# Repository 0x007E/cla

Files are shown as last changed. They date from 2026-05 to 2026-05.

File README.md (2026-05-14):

  

# `RCL` - RGB Color Lamp

The `RCL` is a board with a set of [APA102](#additional-information) or any other `SPI` controllable `RGB-LED`. The board itself is driven with `5V` over USB and can be configured with the integrated UART interface ([MCP2221A](#additional-information)). The `Color Lamp` itself is controlled over the additional `Touchpad` ([TPD](https://github.com/0x007e/tpd/)) and can be switched on/off over a slide switch.

| Experience  | Level |
|:---|:---:|
| Soldering | ?% |

# Downloads

| Type | File | Description |
|:---:|:---:|:---|
| Schematic | [pdf](https://github.com/0x007E/rcl/releases/latest/download/schematic.pdf) / [cadlab](https://cadlab.io/project/30341/main/files) | Schematic files |
| Board | [pdf](https://github.com/0x007E/rcl/releases/latest/download/pcb.pdf) / [cadlab](https://cadlab.io/project/30341/main/files) | Board file |
| Drill | [pdf](https://github.com/0x007E/rcl/releases/latest/download/drill.pdf) | Drill file |
| PCB | [zip](https://github.com/0x007E/rcl/releases/latest/download/kicad.zip) / [tar](https://github.com/0x007E/rcl/releases/latest/download/kicad.tar.gz) | KiCAD/Gerber/BoM/Drill files |
| Mechanical | [zip](https://github.com/0x007E/rcl/releases/latest/download/freecad.zip) / [tar](https://github.com/0x007E/rcl/releases/latest/download/freecad.tar.gz) | FreeCAD/Housing and exported step/stl files |

# Hardware

The pcb is created with `KiCAD`, the housing with `FreeCAD`. All files are built with `github actions` so that they are ready for a production environment.

## PCB

The circuit board is populated on both sides (Top, Bottom). The best way for soldering the `SMD` components is within a vapor phase soldering system and for the `THT` components with a standard soldering system.

### Top Layer

Top Layer

### Bottom Layer

Bottom Layer

## Mechanical

The housing has a tolerance of `0.2mm` on each side of the case. So the pcb should fit perfectly in the housing. The tolerance can be modified with `FreeCAD` in the `Parameter` Spreadsheet.

### Assembled

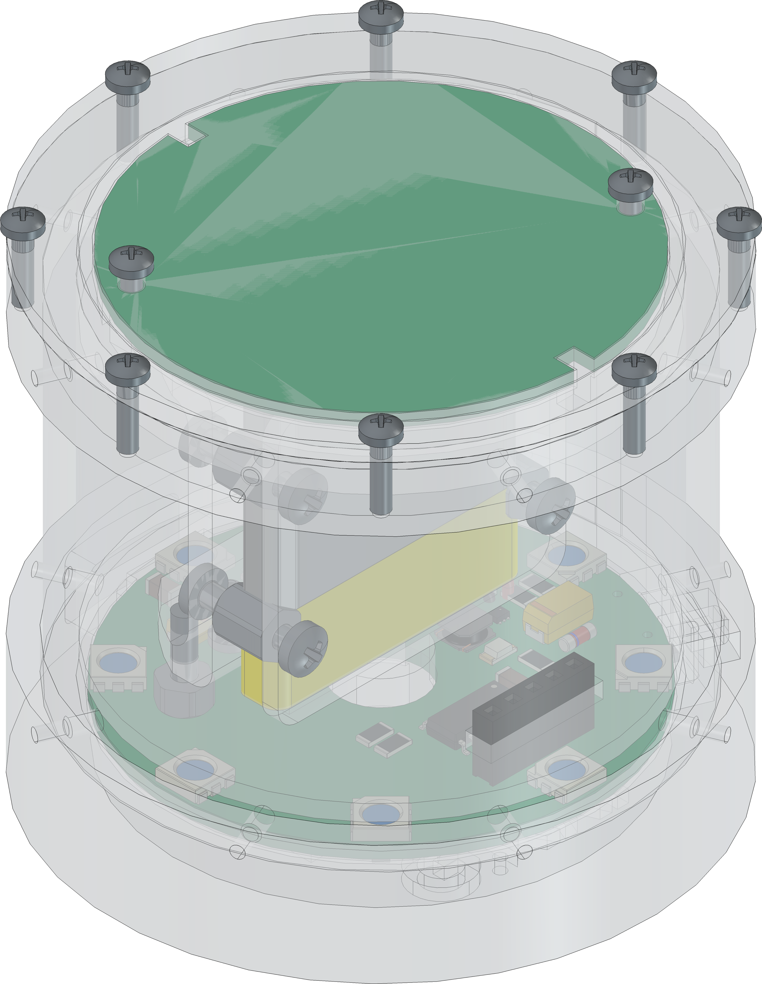
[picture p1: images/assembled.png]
Assembled


### Exploded

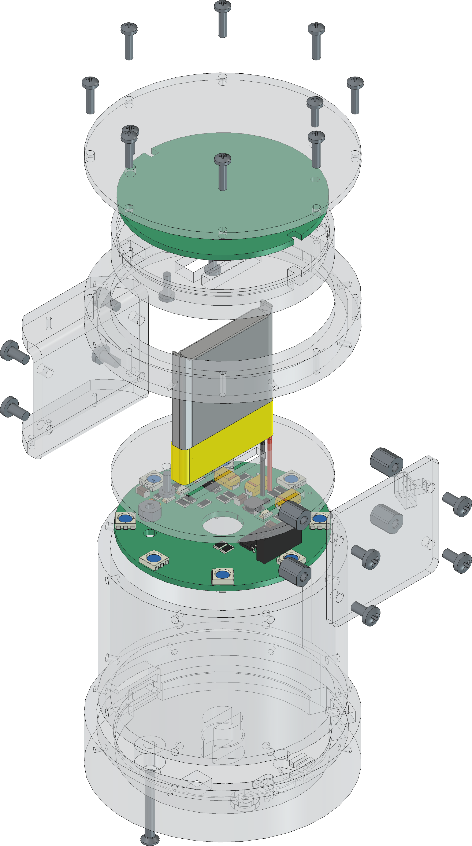
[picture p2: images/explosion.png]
Exploded


# Additional Information

| Type | Link | Description |
|:---:|:---:|:---|
| APA102 | [pdf](https://cdn.sparkfun.com/datasheets/Components/LED/APA102C.pdf) | RGB Full Color LED |
| T3A33BRG | [pdf](https://mm.digikey.com/Volume0/opasdata/d220001/medias/docus/6794/3147_T3A33BRG-H9C0002X1U1930.pdf) | Harvatek Surface Mount PLCC IC+RGB LEDs Data Sheet |
| MCP2221A | [pdf](https://ww1.microchip.com/downloads/en/devicedoc/20005565b.pdf) | USB 2.0 to I2C/UART Protocol Converter with GPIO |

---

R. GAECHTER

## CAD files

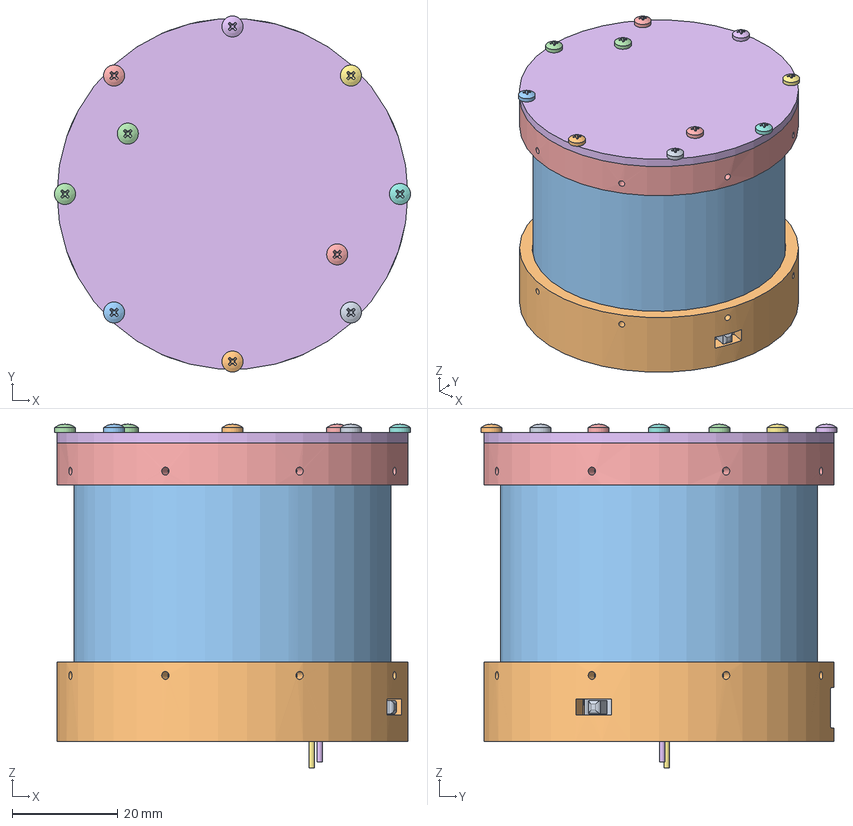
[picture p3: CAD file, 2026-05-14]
mechanical/housing.FCStd
67.4 x 67.4 x 65.1 mm
Pcb_e179
U2_SOT_563_2dd8ecf5d5b2
C7_C_1206_3216Metric_b50edff72533
D17_LED_RGB_5050_6_446c280b42f4
R8_R_1206_3216Metric_683208ab82f3
R7_R_1206_3216Metric_c8e4829b0dbe
R20_R_1206_3216Metric_ada6986ab1e3
U4_SOIC_14_39x87mm_P127mm_a823e2dd6a96
R6_R_1206_3216Metric_a43521a23db1
D8_LED_1206_3216Metric_441c9a4e21c6
R22_R_1206_3216Metric_ec401104cd5b
R2_R_1206_3216Metric_38918280b1d4
J3_PinSocket_1x05_P254mm_Vertical_10db449187f2
D10_LED_RGB_5050_6_a057058c2c85
D14_LED_RGB_5050_6_f9c46359ebbe
C5_CP_EIA_6032_28_Kemet_C_9ff8ca105aa5
C6_CP_EIA_6032_28_Kemet_C_5cea3e5c8aeb
D9_LED_1206_3216Metric_51ed994f9992
U1_MSOP_10_3x3mm_P05mm_71ae01295b95
D3_LED_1206_3216Metric_cbb3f32ba383
D16_LED_RGB_5050_6_b71b78d54b77
D15_LED_RGB_5050_6_33237c4f53fe
R26_R_1206_3216Metric_9c2edd1c9367
D7_LED_1206_3216Metric_bb91850a56bd
D12_LED_RGB_5050_6_03ddc8fedd98
R1_R_1206_3216Metric_1c8ffaa0bde6
D11_LED_RGB_5050_6_1851560dca97
C8_CP_EIA_6032_28_Kemet_C_c15ccf4b1ffd
Pins
Pins001
Sealant
wire
wire001
R3_R_1206_3216Metric_5ddc5bbf8b34
D13_LED_RGB_5050_6_6a2bdbbd2506
D2_D_MiniMELF_Standard_6b93bcc5f046
R27_R_1206_3216Metric_52032e25f07e
F2_Fuse_1206_3216Metric_555ae69b6f8a
C13_C_1206_3216Metric_f1310714ac0f
R25_R_1206_3216Metric_a714514fdd53
R5_R_1206_3216Metric_4461fe18ce72
C10_C_1206_3216Metric_f1c43b265332
C3_CP_EIA_3528_21_Kemet_B_289e8f7c64f1
C16_C_1206_3216Metric_33e90888eea0
C2_C_1206_3216Metric_edaf30bb730d
C4_C_1206_3216Metric_e27ebc430218
D1_D_SMA_fda0fc89879e
C12_C_1206_3216Metric_5ff6f1587083
C15_C_1206_3216Metric_d52032bb3cd0
R9_R_1206_3216Metric_4f6db5270b56
SW3_SW_SPST_PTS645_fdfa39aaf73e
J2_JST_S2B_PH_K_a3ec8615dd23
R13_R_1206_3216Metric_72071d534f4d
C19_C_1206_3216Metric_a9e1a73ff39b
C20_C_1206_3216Metric_c22b4fc6462b
D6_D_MiniMELF_Standard_ccd223f269fd
U3_SOIC_8_39x49mm_P127mm_1d457f73bb48
Q2_SOT_23_310fab92fd9c
C18_C_1206_3216Metric_0231d3197693
R15_R_1206_3216Metric_49b70c382772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

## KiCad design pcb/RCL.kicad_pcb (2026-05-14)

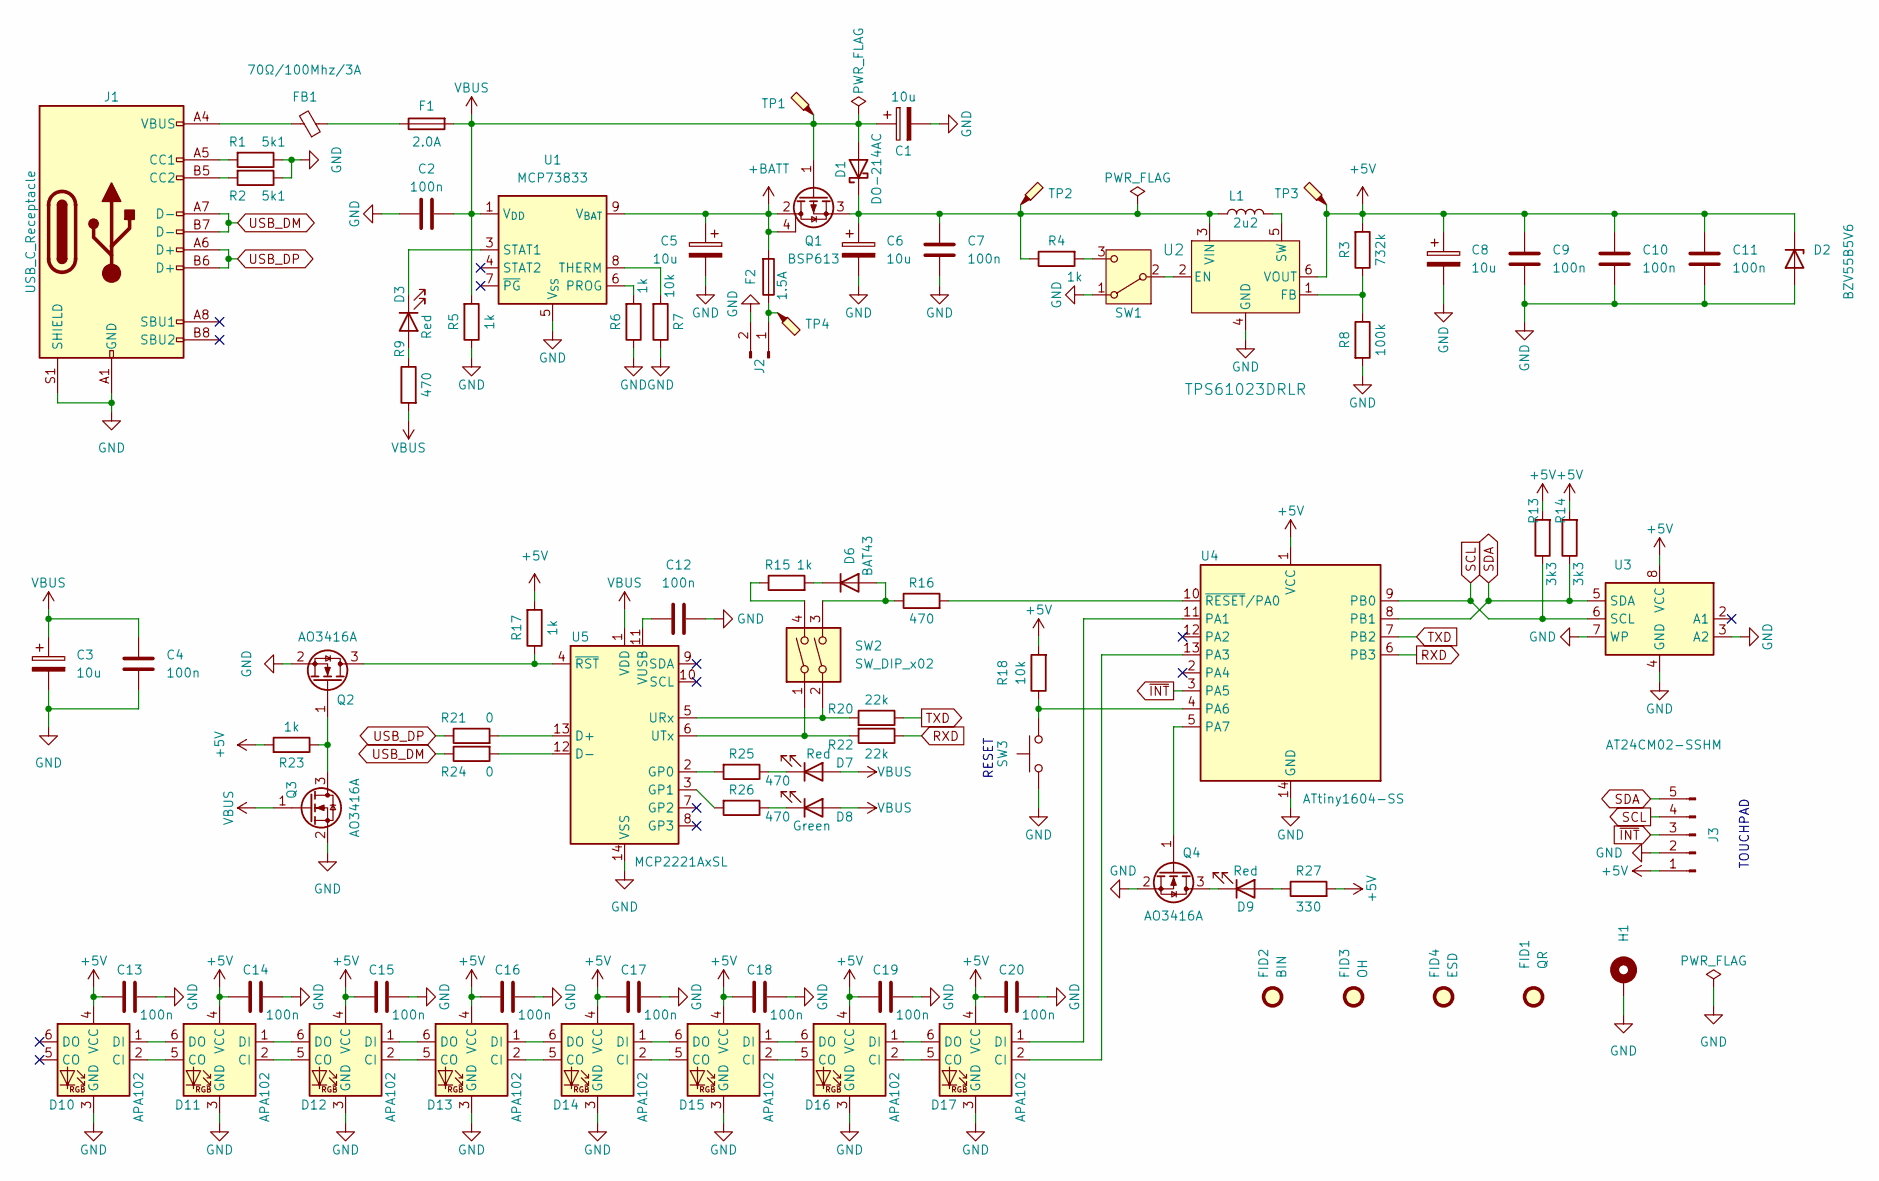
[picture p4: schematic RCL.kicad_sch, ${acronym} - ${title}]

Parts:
C1, C5, C6, C8: 10u; CP_EIA-6032-28_Kemet-C
C2, C4, C7, C9, C10, C11, C12, C13, C14, C15, C16, C17, C18, C19, C20: 100n; C_1206_3216Metric
C3: 10u; CP_EIA-3528-21_Kemet-B
D1: DO-214AC; D_SMA
D2: BZV55B5V6; D_MiniMELF
D3, D7, D9: Red; LED_1206_3216Metric
D6: BAT43; D_MiniMELF
D8: Green; LED_1206_3216Metric
D10, D11, D12, D13, D14, D15, D16, D17: APA102; LED_RGB_5050-6
F1: 2.0A; Fuse_1206_3216Metric
F2: 1.5A; Fuse_1206_3216Metric
FB1: 70Ω/100Mhz/3A; L_1206_3216Metric
FID1: QR; QR_0x007e_very_small
FID2: BIN; WEEE-Logo_4.2x6mm_SilkScreen
FID3: OH; OSHW-Logo2_7.3x6mm_SilkScreen
FID4: ESD; ESD-Logo_6.6x6mm_SilkScreen
H1: MountingHole_Pad; MountingHole_3.2mm_M3_DIN965_Pad
J1: USB_C_Receptacle; USB_C_Receptacle_GCT_USB4110
J2: Conn_01x02_Pin; JST_PH_S2B-PH-K_1x02_P2.00mm_Horizontal
J3: Conn_01x05_Pin; PinSocket_1x05_P2.54mm_Vertical
L1: 2u2; L_Vishay_IFSC-1515AH_4x4x1.8mm
Q1: BSP613; SOT-223
Q2, Q3, Q4: AO3416A; SOT-23
R1, R2: 5k1; R_1206_3216Metric
R3: 732k; R_1206_3216Metric
R4, R5, R6, R15, R17, R23: 1k; R_1206_3216Metric
R7, R18: 10k; R_1206_3216Metric
R8: 100k; R_1206_3216Metric
R9, R16, R25, R26: 470; R_1206_3216Metric
R13, R14: 3k3; R_1206_3216Metric
R20, R22: 22k; R_1206_3216Metric
R21, R24: 0; R_0603_1608Metric
R27: 330; R_1206_3216Metric
SW1: SW_SPDT; SW_SPDT_CK_JS102011SAQN
SW2: SW_DIP_x02; SW_DIP_SPSTx02_Slide_6.7x6.64mm_W8.61mm_P2.54mm_LowProfile
SW3: SW_Push; SW_SPST_PTS645
TP1, TP2, TP3, TP4: TestPoint_Probe; TestPoint_Pad_D1.0mm
U1: MCP73833; MSOP-10_3x3mm_P0.5mm
U2: TPS61023DRLR; SOT-563
U3: AT24CM02-SSHM; SOIC-8_3.9x4.9mm_P1.27mm
U4: ATtiny1604-SS; SOIC-14_3.9x8.7mm_P1.27mm
U5: MCP2221AxSL; SOIC-14_3.9x8.7mm_P1.27mm

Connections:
+5V: C8.1, C9.1, C10.1, C11.1, C13.2, C14.2, C15.2, C16.2, C17.2, C18.2, C19.2, C20.2, D2.1 (K), D10.4 (VCC), D11.4 (VCC), D12.4 (VCC), D13.4 (VCC), D14.4 (VCC), D15.4 (VCC), D16.4 (VCC), D17.4 (VCC), J3.1, R3.2, R13.2, R14.2, R17.2, R18.2, R23.2, R27.2, TP3.1, U2.6 (VOUT), U3.8 (VCC), U4.1 (VCC)
+BATT: C5.1, F2.2, Q1.2 (D), Q1.4 (D), U1.9 (V_{BAT}), U1.10 (V_{BAT})
GND: C1.2, C2.2, C3.2, C4.2, C5.2, C6.2, C7.2, C8.2, C9.2, C10.2, C11.2, C12.2, C13.1, C14.1, C15.1, C16.1, C17.1, C18.1, C19.1, C20.1, D2.2 (A), D10.3 (GND), D11.3 (GND), D12.3 (GND), D13.3 (GND), D14.3 (GND), D15.3 (GND), D16.3 (GND), D17.3 (GND), H1.1, J1.A1 (GND), J1.A12 (GND), J1.B1 (GND), J1.B12 (GND), J1.S1 (SHIELD), J2.2, J3.2, Q2.2 (S), Q3.2 (S), Q4.2 (S), R1.1, R2.1, R5.1, R6.1, R7.1, R8.2, SW1.1 (A), SW3.1, U1.5 (V_{SS}), U2.4 (GND), U3.3 (A2), U3.4 (GND), U3.7 (WP), U4.14 (GND), U5.14 (VSS)
unnamed: C6.1, C7.1, D1.1 (K), L1.1, Q1.3 (S), R4.1, TP2.1, U2.3 (VIN)
unnamed: D3.2 (A), R9.1
unnamed: D3.1 (K), U1.3 (STAT1)
unnamed: D6.2 (A), R16.1, SW2.3
unnamed: D6.1 (K), R15.2
unnamed: D7.1 (K), R25.1
unnamed: D8.1 (K), R26.1
unnamed: D9.2 (A), R27.1
unnamed: D9.1 (K), Q4.3 (D)
unnamed: D10.2 (CI), D11.5 (CO)
unnamed: D10.1 (DI), D11.6 (DO)
unnamed: D11.2 (CI), D12.5 (CO)
unnamed: D11.1 (DI), D12.6 (DO)
unnamed: D12.2 (CI), D13.5 (CO)
unnamed: D12.1 (DI), D13.6 (DO)
unnamed: D13.2 (CI), D14.5 (CO)
unnamed: D13.1 (DI), D14.6 (DO)
unnamed: D14.2 (CI), D15.5 (CO)
unnamed: D14.1 (DI), D15.6 (DO)
unnamed: D15.2 (CI), D16.5 (CO)
unnamed: D15.1 (DI), D16.6 (DO)
unnamed: D16.2 (CI), D17.5 (CO)
unnamed: D16.1 (DI), D17.6 (DO)
unnamed: D17.2 (CI), U4.13 (PA3)
unnamed: D17.1 (DI), U4.11 (PA1)
unnamed: F1.1, FB1.1
unnamed: FB1.2, J1.A4 (VBUS), J1.A9 (VBUS), J1.B4 (VBUS), J1.B9 (VBUS)
unnamed: J1.A5 (CC1), R1.2
unnamed: J1.B5 (CC2), R2.2
unnamed: F2.1, J2.1, TP4.1
unnamed: Q2.3 (D), R17.1, U5.4 (~RST)
unnamed: Q2.1 (G), Q3.3 (D), R23.1
unnamed: Q4.1 (G), U4.5 (PA7)
unnamed: R15.1, SW2.4
unnamed: SW1.2 (B), U2.2 (EN)
unnamed: R4.2, SW1.3 (C)
unnamed: R6.2, U1.6 (PROG)
unnamed: R7.2, U1.8 (THERM)
unnamed: R3.1, R8.1, U2.1 (FB)
unnamed: L1.2, U2.5 (SW)
unnamed: R18.1, SW3.2, U4.4 (PA6)
unnamed: R16.2, U4.10 (~RESET/PA0)
unnamed: R21.2, U5.13 (D+)
unnamed: R24.2, U5.12 (D-)
unnamed: R25.2, U5.2 (GP0)
unnamed: R26.2, U5.3 (GP1)
unnamed: R20.2, SW2.2, U5.5 (URx)
unnamed: R22.2, SW2.1, U5.6 (UTx)
unnamed: C12.1, U5.11 (VUSB)
RXD: R22.1, U4.6 (PB3)
SCL: J3.4, R13.1, U3.6 (SCL), U4.9 (PB0)
SDA: J3.5, R14.1, U3.5 (SDA), U4.8 (PB1)
TXD: R20.1, U4.7 (PB2)
USB_DM: J1.A7 (D-), J1.B7 (D-), R24.1
USB_DP: J1.A6 (D+), J1.B6 (D+), R21.1
VBUS: C1.1, C2.1, C3.1, C4.1, D1.2 (A), D7.2 (A), D8.2 (A), F1.2, Q1.1 (G), Q3.1 (G), R5.2, R9.2, TP1.1, U1.1 (V_{DD}), U1.2 (V_{DD}), U5.1 (VDD)
~INT: J3.3, U4.3 (PA5)

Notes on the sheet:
TOUCHPAD
RESET

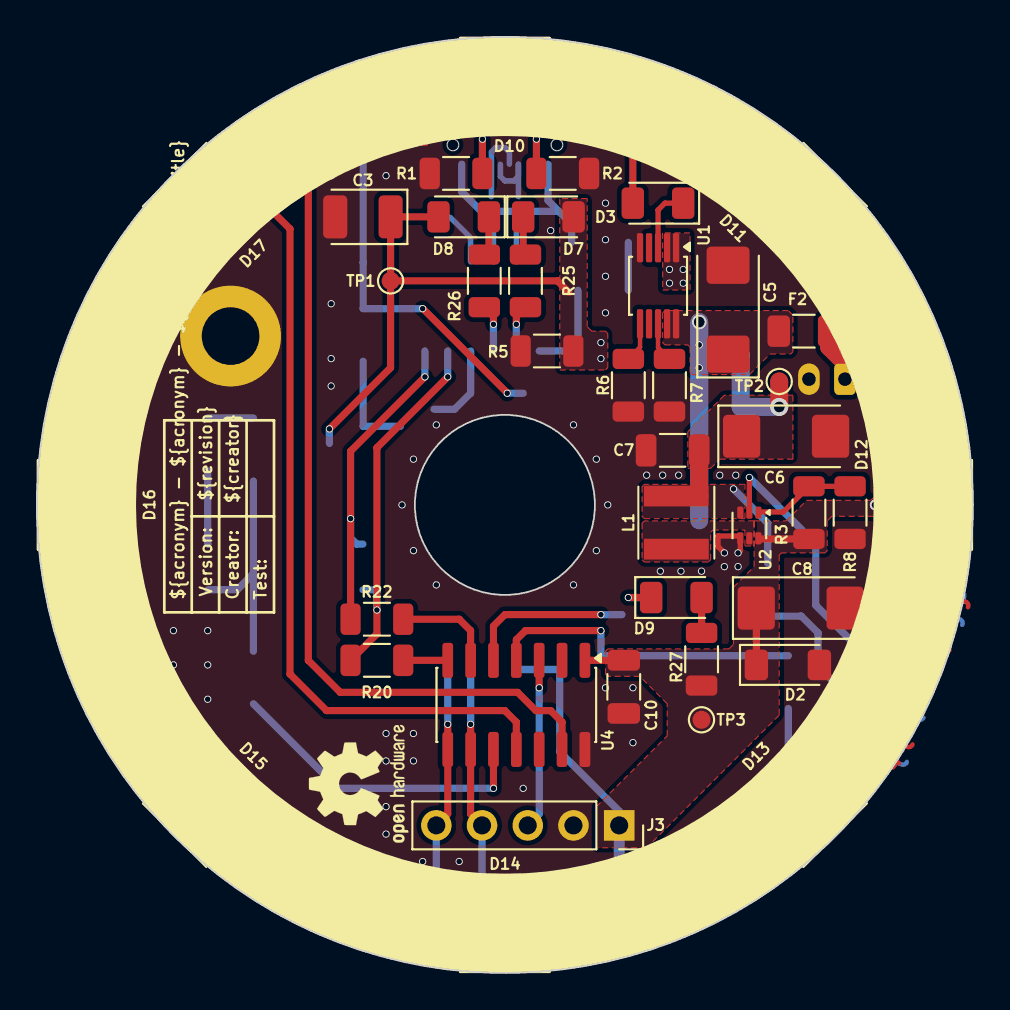
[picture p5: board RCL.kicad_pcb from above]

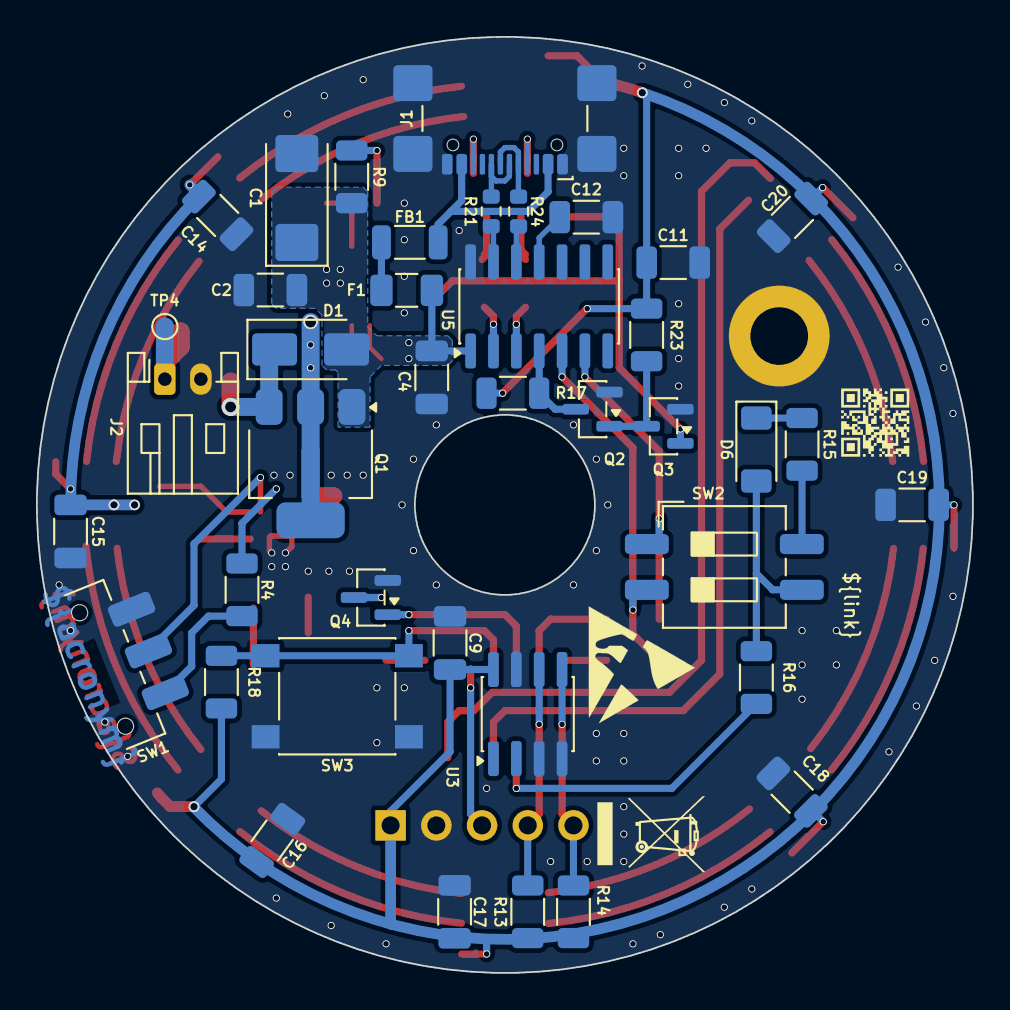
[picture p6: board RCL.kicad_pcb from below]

Board: 2 copper layers, 52.0 x 52.0 mm, 86 parts (43 on the bottom side), 60 nets.

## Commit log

2026-04-24 Add pcb layout
    [RCL.kicad_pcb, RCL.kicad_sch]
2026-04-27 Add mechanical parts
    [housing.FCStd]
2026-04-27 Add dimensioning
    [RCL.kicad_pcb, RCL.kicad_sch]
2026-04-27 Move screw position
    [housing.FCStd]
2026-05-02 Add missing vendor(id)
    [RCL.kicad_pcb, RCL.kicad_sch]
2026-05-14 Add assembly explosion
    [housing.FCStd]
2026-05-14 Increase KiCAD version
    [RCL.kicad_pcb, RCL.kicad_sch]
2026-05-14 Remove unnecessary drc filters

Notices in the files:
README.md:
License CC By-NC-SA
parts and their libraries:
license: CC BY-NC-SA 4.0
